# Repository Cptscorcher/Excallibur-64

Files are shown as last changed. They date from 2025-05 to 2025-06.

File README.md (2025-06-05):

# Excallibur-64
A reimagining of the seminal Excalibur 64 Computer
This is version 3 - yet to be tested but fixed a few things from version 2. Currently there are still some components that rely on 3rd party libraries and don't need to be, so in the process of removing them to make it more portable. 
There is no video yet, that is a separate beast. 

Goal for this project
=====================
Design build a new version of the  Excalibur 64. First major goal is to get all but the video going. So need to write firmware to take input from the keyboard output text via the serial port. 
Final version will have video as per original design.

Design requirements
==================
1. Needs to have the same look and feel of a real Excalibur 64. So the circuit for the sound and, parallel and keyboard is the same but with CMOS where possible.
2. Same goes for the video but need to think about a work around for the 6331-1 PROM.
3. There are some differences for practically and cost. For example using a single SRAM and single Flash ROM instead of two ROMs. Burning ROMs is a pain maybe when I do a 'pitch perfect' PCB I'll use DRAM and PROMS. The power supply is also different. At $25 I'm not using a LM323 for a +5 reg and since we are using a RS232 line driver IC there is no need for -12v. The reset circuit is different, that was simply because I don't understand how the original reset circuit worked. Its great to be authentic but a different power circuit isn't going to change the experience.

Future plans
============
1. Build a Disk Drive controller based on the WD2793 as per the original.
2. Build a HI-RES board.
3. Build some of the other board featured in the Excalibur 64 users group.
4. All the parts used on the original are still available so would be great to build one as the founders intended. All hail the founders!!

Credits
=======
All the original schematics + more is available from https://www.microbee-mspp.org/repository/ . Info from here was what this design is based on.

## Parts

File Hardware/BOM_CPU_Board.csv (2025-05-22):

Reference | Value | Qty | DNP
C7,C121,C123,C124,C125,C126 | 1uF | 6
C19,C101 | 4.7uF | 2
C25 | 56nF | 1
C26 | 10uF | 1
C102,C103,C104,C105,C106,C108,C109,C111,C112,C113,C114,C115,C116,C117,C118,C119,C120,C129,C130,C131 | 10nf | 20
C107,C128 | 33p | 2
C110 | 1000uF | 1
C122 | 100uF | 1
C127 | 100pf | 1
D1,D2,D3,D4,D5,D6,D7,D8,D21,D22,D104 | 1N4148 | 11
D101 | 5v | 1
D102 | 1N4448 | 1
D103 | 12v | 1
DZ101 | BZX79-B2V4 | 1
IC1 | 74HCT244 | 1
IC15 | 8253 | 1
IC16 | Z84C00 | 1
IC18 | 74HC139 | 1
IC22 | 8251 | 1
IC25,IC32 | 74HC138 | 2
IC27 | 74HC32 | 1
IC28 | 74HC00 | 1
IC29 | 74HC04 | 1
IC30 | 74HC02 | 1
IC31 | 74HC273 | 1
IC35 | 82C55A | 1
IC42 | LM348N | 1
IC49 | 74HC367 | 1
IC54 | 74HC123 | 1
IC56 | 74HC161 | 1
IC102 | MAX232 | 1
IC110 | SST39SF010 | 1
IC111 | HM62256ALSP | 1
J3 | Ext Clk | 1
J4 | Expansion | 1
J7 | Decoder | 1
J101 | CS Test Points | 1
J102 | Tx | 1
J103 | Rx | 1
J104 | SPEAKER (AUDIO) | 1
J105 | TTL Serial | 1
J107 | Power In | 1
J108 | CASSETTE | 1
J109 | RTS - DSR | 1
J110 | PARALLEL OUTPUT PORT | 1
J111 | Keyboard | 1
J112 | Serial | 1
LED1 | SST0 | 1
LED2 | SST1 | 1
LED3 | SST2 | 1
LED4 | Not Used | 1
LED101,LED103 | Red | 2
LED102,LED104 | Green | 2
Q1,Q102 | BC548 | 2
Q101 | 2N2222A-TO92 | 1
R17,R104,R110,R112,R113,RN101 | 10K | 6
R18,R23,R25,R111 | 2K2 | 4
R19,R21,R114 | 18K | 3
R20,R115 | 18 | 2
R22,R105 | 1K | 2
R24 | 68K | 1
R28,R29,R30,R31 | 4k7 | 4
R38 | 10 | 1
R39 | 820 | 1
R101 | 220 | 1
R102 | 100K | 1
R103,R106,RN2 | 4K7 | 3
R107 | 6K8 | 1
R108,R109,R116,R117,R142,R143,R144,R145 | 90 | 8
R118 | 560 | 1
R119 | 360 | 1
R120 | 1M | 1
SW101 | Reset | 1
TP101,XTAL2 | 16Mhz | 2
TP102 | TestPoint | 1
U101 | 74HC14 | 1
U102 | LM7805CT | 1
U103 | LM7812CT | 1

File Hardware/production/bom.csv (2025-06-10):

Designator | Footprint | Quantity | Value | LCSC Part #
C1 | CP_Radial_D14.0mm_P5.00mm | 1 | 1000Uf
C10, C11, C12, C13, C14, C15, C16, C17, C18, C19, C20, C21, C22, C23, C24, C27, C5, C6, C8, C9 | C_Disc_D4.3mm_W1.9mm_P5.00mm | 20 | 10nF
C121, C123, C124, C125, C126, C7 | CP_Radial_D6.3mm_P2.50mm | 6 | 1uF
C127 | C_Disc_D3.4mm_W2.1mm_P2.50mm | 1 | 100pf
C2, C3 | CP_Radial_D8.0mm_P5.00mm | 2 | 4.7uF
C25 | 0603 | 1 | 56nF
C26 | CP_Radial_D5.0mm_P2.50mm | 1 | 10uF
C29, C30 | C_Disc_D3.0mm_W1.6mm_P2.50mm | 2 | 33p
C4 | CP_Radial_D8.0mm_P5.00mm | 1 | 100uF
D1, D12, D13, D2, D3, D4, D5, D6, D7, D8 | D_DO-35_SOD27_P7.62mm_Horizontal | 10 | 1N4148
D10 | LED_D5.0mm | 1 | GREEN
D11 | D_DO-35_SOD27_P7.62mm_Horizontal | 1 | 1N4448
D14, D9 | LED_D5.0mm | 2 | RED
D15 | 1206 | 1 | SST0
D16 | 1206 | 1 | SST1
D17 | 1206 | 1 | SST2
D18 | 1206 | 1 | Not Used
DZ101 | D_DO-35_SOD27_P7.62mm_Horizontal | 1 | BZX79-B2V4
IC1 | DIP-20_W7.62mm_LongPads | 1 | 74HCT244
IC102 | DIP-16_W7.62mm_LongPads | 1 | MAX232
IC110 | DIP_Socket-32_W11.9_W12.7_W15.24_W17.78_W18.5_3M_232-1285-00-0602J | 1 | SST39SF010
IC111 | DIP-28_W15.24mm | 1 | HM62256ALSP
IC15 | DIP-24_W15.24mm | 1 | 8253
IC16 | DIP-40_W15.24mm_LongPads | 1 | Z80 CPU
IC18 | DIP-16_W7.62mm_Socket_LongPads | 1 | 74HC139
IC22 | DIP-28_W15.24mm_LongPads | 1 | 8251
IC25 | DIP-16_W7.62mm_LongPads | 1 | 74HC138
IC27 | DIP-14_W7.62mm_LongPads | 1 | 74HC32
IC29 | DIP-14_W7.62mm_Socket_LongPads | 1 | 74AHC04
IC31 | DIP-20_W7.62mm_Socket | 1 | 74HC273
IC32 | DIP-16_W7.62mm_Socket_LongPads | 1 | 74HC138
IC35 | DIP-40_W15.24mm | 1 | 82C55A
IC42 | DIP-14_W7.62mm_LongPads | 1 | LM348N
IC49 | DIP-16_W7.62mm_Socket_LongPads | 1 | 74HC367
IC54 | DIP-16_W7.62mm_LongPads | 1 | 74HC123
IC56 | DIP-16_W7.62mm_Socket_LongPads | 1 | 74HC161
J1 | DIN_5 | 1 | POWER
J101 | PinHeader_1x09_P2.54mm_Vertical | 1 | CS Test Points
J102 | PinHeader_1x02_P2.54mm_Vertical | 1 | Tx
J103 | PinHeader_1x02_P2.54mm_Vertical | 1 | Rx
J104 | PinSocket_1x03_P2.54mm_Vertical | 1 | SPEAKER
J105 | PinHeader_1x06_P2.54mm_Vertical | 1 | TTL Serial
J106 | PinHeader_1x03_P2.54mm_Vertical | 1 | UpperROM
J108 | DIN_5 | 1 | CASSETTE
J109 | PinHeader_1x02_P2.54mm_Vertical | 1 | RTS - DSR
J110 | IDC-Header_2x17_P2.54mm_Latch_Horizontal | 1 | PARALLEL OUTPUT PORT
J111 | PinHeader_2x08_P2.54mm_Vertical | 1 | Keyboard
J112 | DSUB-9_Pins_Horizontal_P2.77x2.84mm_EdgePinOffset4.94mm_Housed_MountingHolesOffset4.94mm | 1 | Serial
J2 | PinHeader_1x02_P2.54mm_Vertical | 1 | PC
J3 | PinHeader_1x04_P2.54mm_Vertical | 1 | Power In
J4 | PinHeader_2x22_P2.54mm_Vertical | 1 | Expansion
J7 | PinHeader_1x09_P2.54mm_Vertical | 1 | Decoder
LED101, LED103 | 1206 | 2 | Red
LED102, LED104 | 1206 | 2 | Green
Q1, Q2 | TO-92_HandSolder | 2 | BC548
Q101 | TO-92_Inline | 1 | BC548
R1, R10 | R_Axial_DIN0207_L6.3mm_D2.5mm_P10.16mm_Horizontal | 2 | 560
R107 | R_Axial_DIN0207_L6.3mm_D2.5mm_P10.16mm_Horizontal | 1 | 6K8
R108, R109, R116, R117, R142, R143, R144, R145 | 1206 | 8 | 90
R110, R112, R113, R17, R3 | R_Axial_DIN0207_L6.3mm_D2.5mm_P10.16mm_Horizontal | 5 | 10K
R111, R18, R23, R25 | R_Axial_DIN0207_L6.3mm_D2.5mm_P10.16mm_Horizontal | 4 | 2K2
R114, R19, R21 | R_Axial_DIN0207_L6.3mm_D2.5mm_P10.16mm_Horizontal | 3 | 18K
R115, R20 | R_Axial_DIN0207_L6.3mm_D2.5mm_P10.16mm_Horizontal | 2 | 18
R2 | R_Axial_DIN0207_L6.3mm_D2.5mm_P10.16mm_Horizontal | 1 | 220
R22, R4 | R_Axial_DIN0207_L6.3mm_D2.5mm_P10.16mm_Horizontal | 2 | 1K
R24 | R_Axial_DIN0207_L6.3mm_D2.5mm_P10.16mm_Horizontal | 1 | 68K
R38 | R_Axial_DIN0207_L6.3mm_D2.5mm_P10.16mm_Horizontal | 1 | 10
R39 | R_Axial_DIN0207_L6.3mm_D2.5mm_P10.16mm_Horizontal | 1 | 820
R5, R6 | R_Axial_DIN0207_L6.3mm_D2.5mm_P10.16mm_Horizontal | 2 | 4.7k
R7 | R_Axial_DIN0207_L6.3mm_D2.5mm_P10.16mm_Horizontal | 1 | 100k
R8 | R_Axial_DIN0207_L6.3mm_D2.5mm_P10.16mm_Horizontal | 1 | 1M
R9 | R_Axial_DIN0207_L6.3mm_D2.5mm_P10.16mm_Horizontal | 1 | 360
RN1, RN101 | R_Array_SIP5 | 2 | 10K
RN2 | R_Array_SIP9 | 1 | 10k
SW1 | MFS201N-16-Z_NDC | 1 | Power
SW101 | Tact_switch_angled | 1 | Reset
TP1, TP102 | TestPoint_Plated_Hole_D2.0mm | 2 | GND
TP101 | TestPoint_Loop_D1.80mm_Drill1.0mm_Beaded | 1 | 16Mhz
U101 | DIP-14_W7.62mm_Socket_LongPads | 1 | 74AHCU04
U104 | DIP-14_W7.62mm_Socket_LongPads | 1 | 74HC86
U2 | TO-220-3_Vertical | 1 | L7805
XTAL2 | Crystal_HC49-U_Vertical | 1 | 16Mhz

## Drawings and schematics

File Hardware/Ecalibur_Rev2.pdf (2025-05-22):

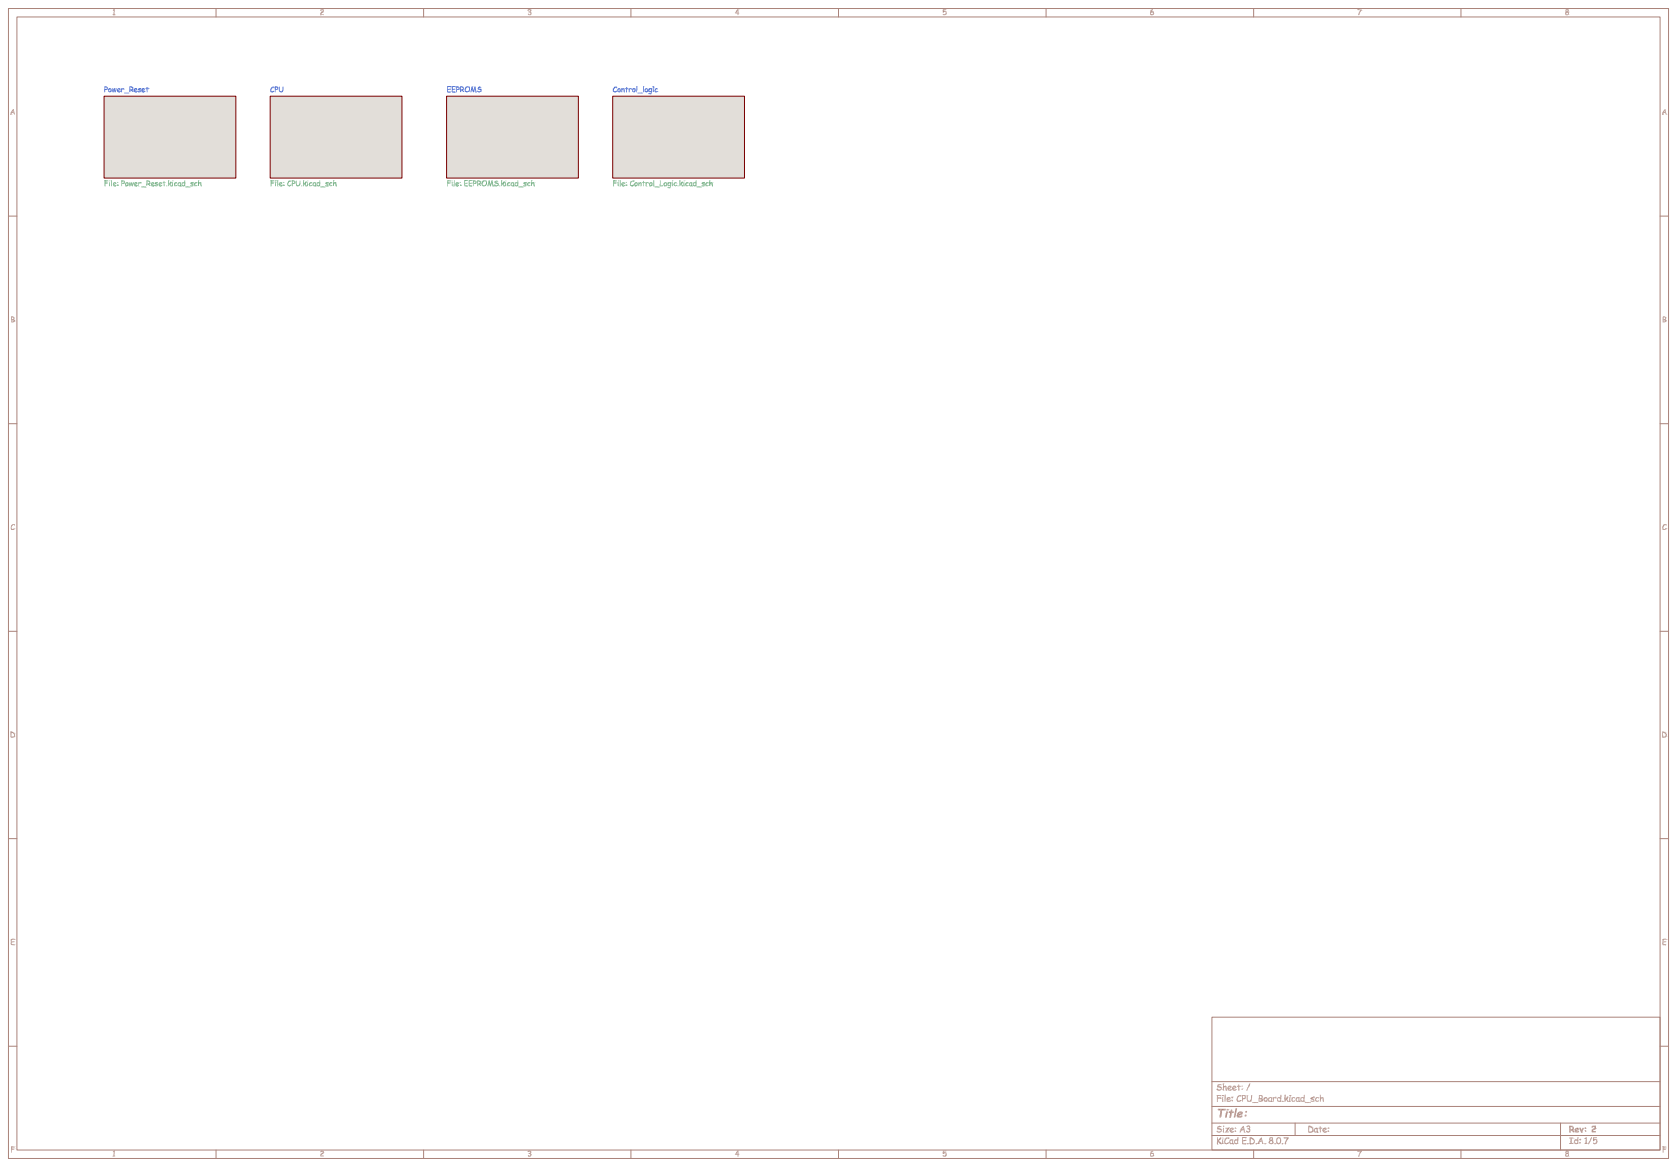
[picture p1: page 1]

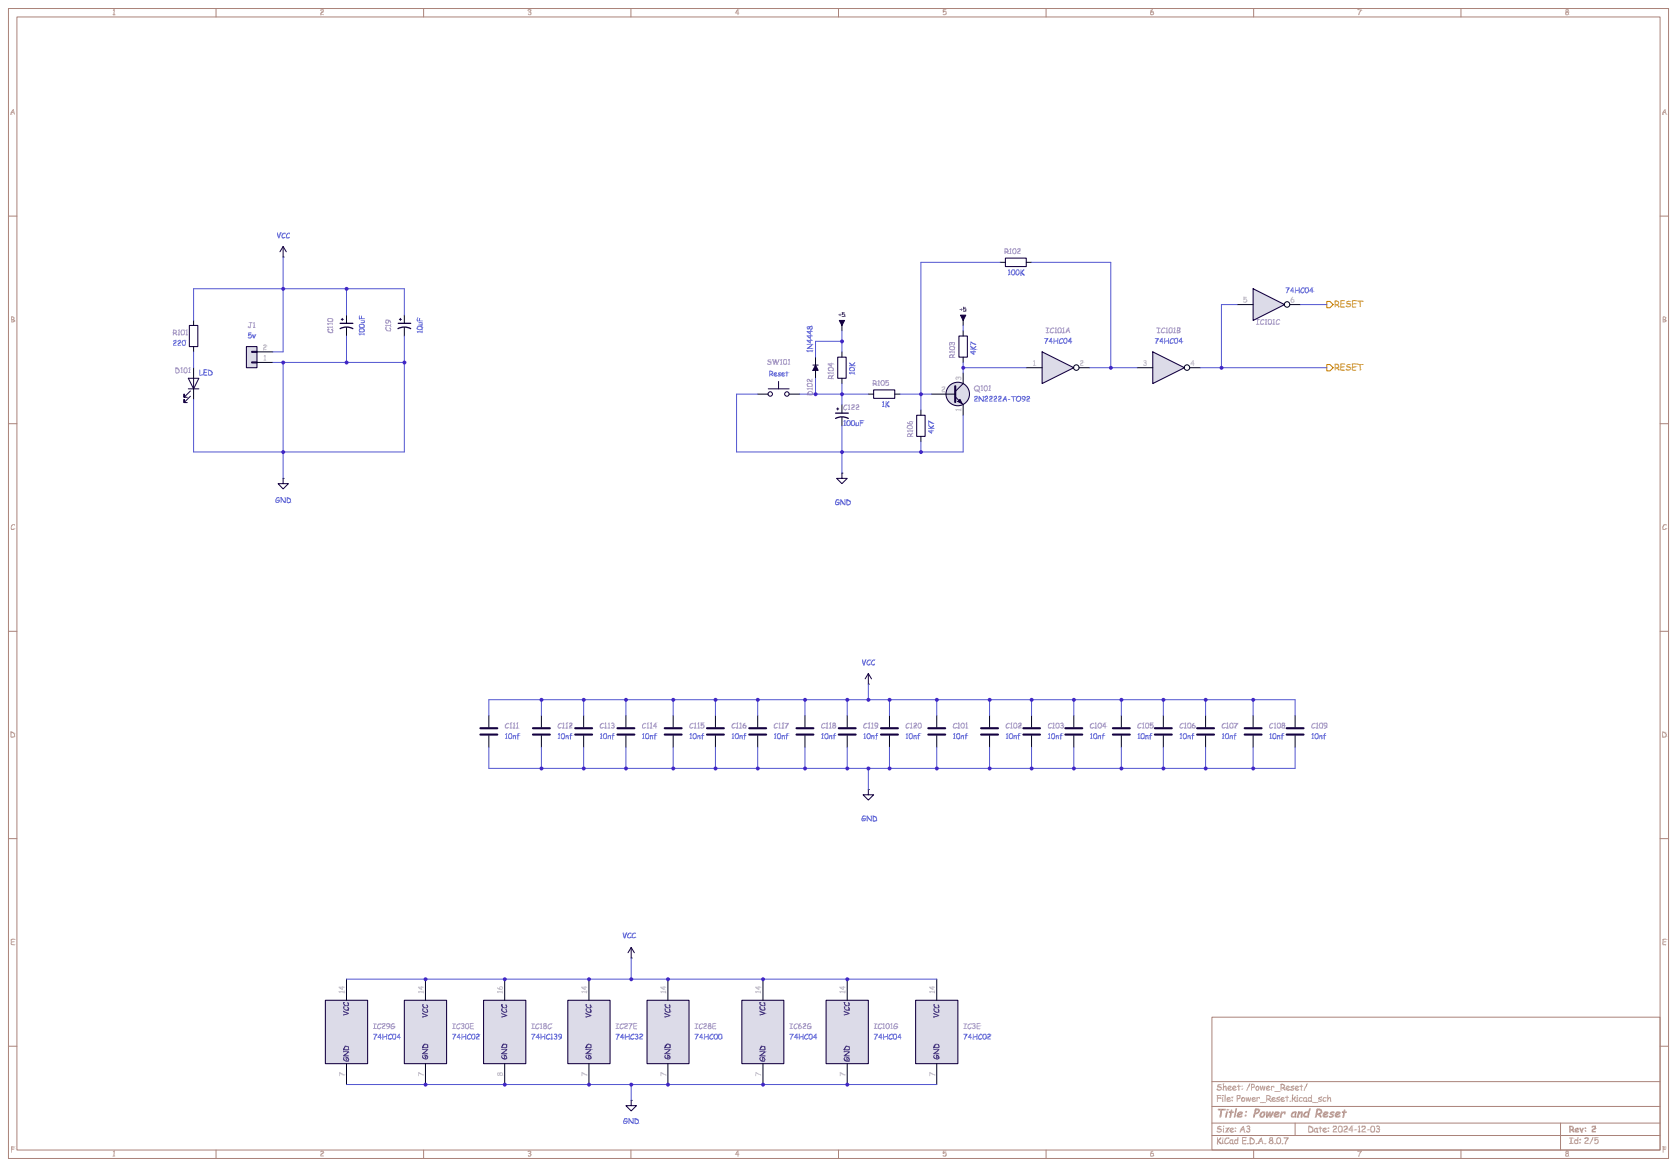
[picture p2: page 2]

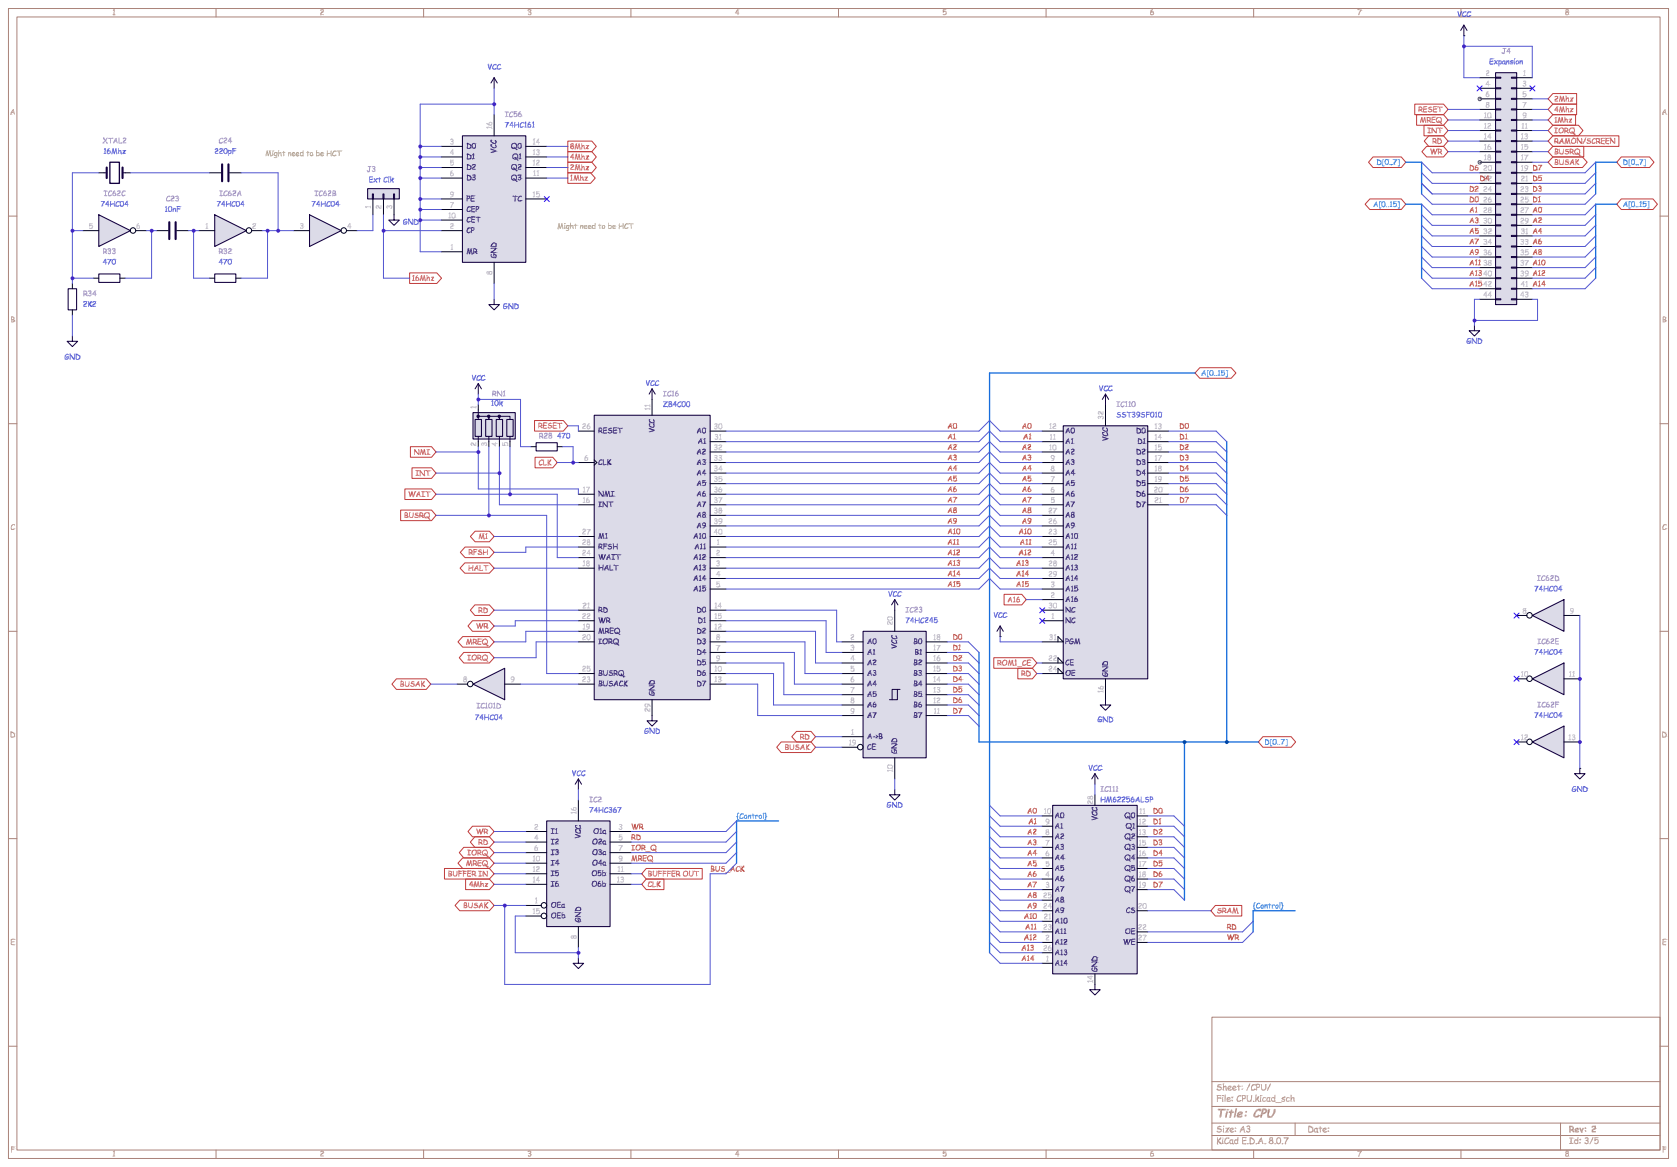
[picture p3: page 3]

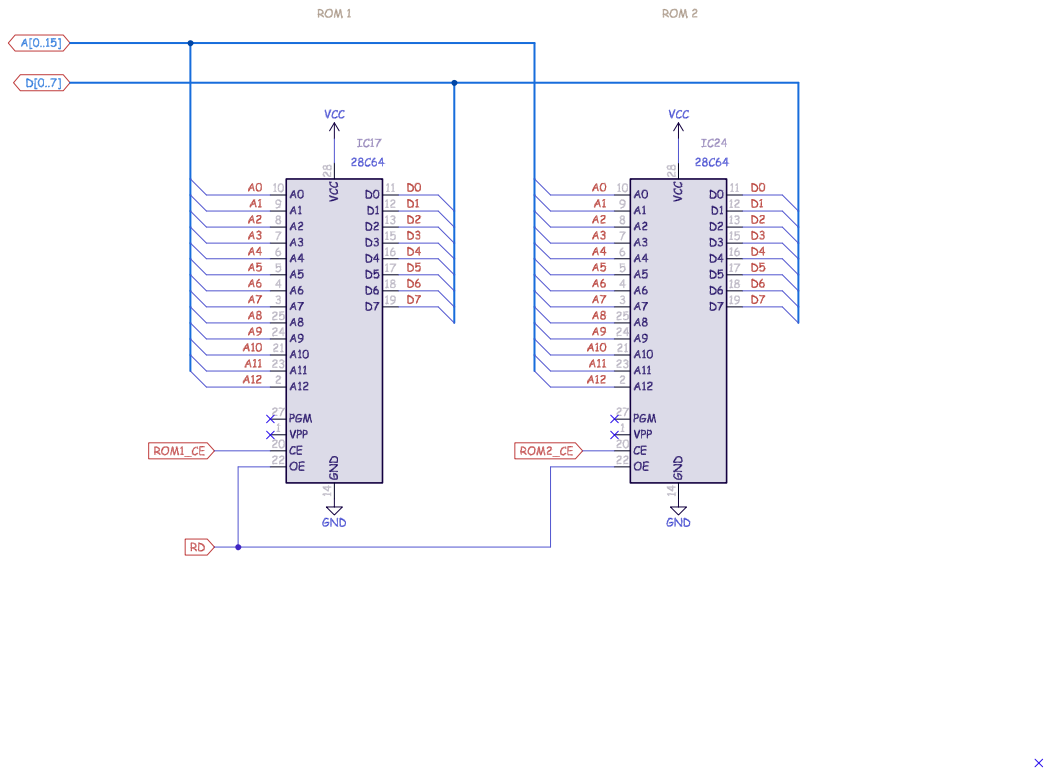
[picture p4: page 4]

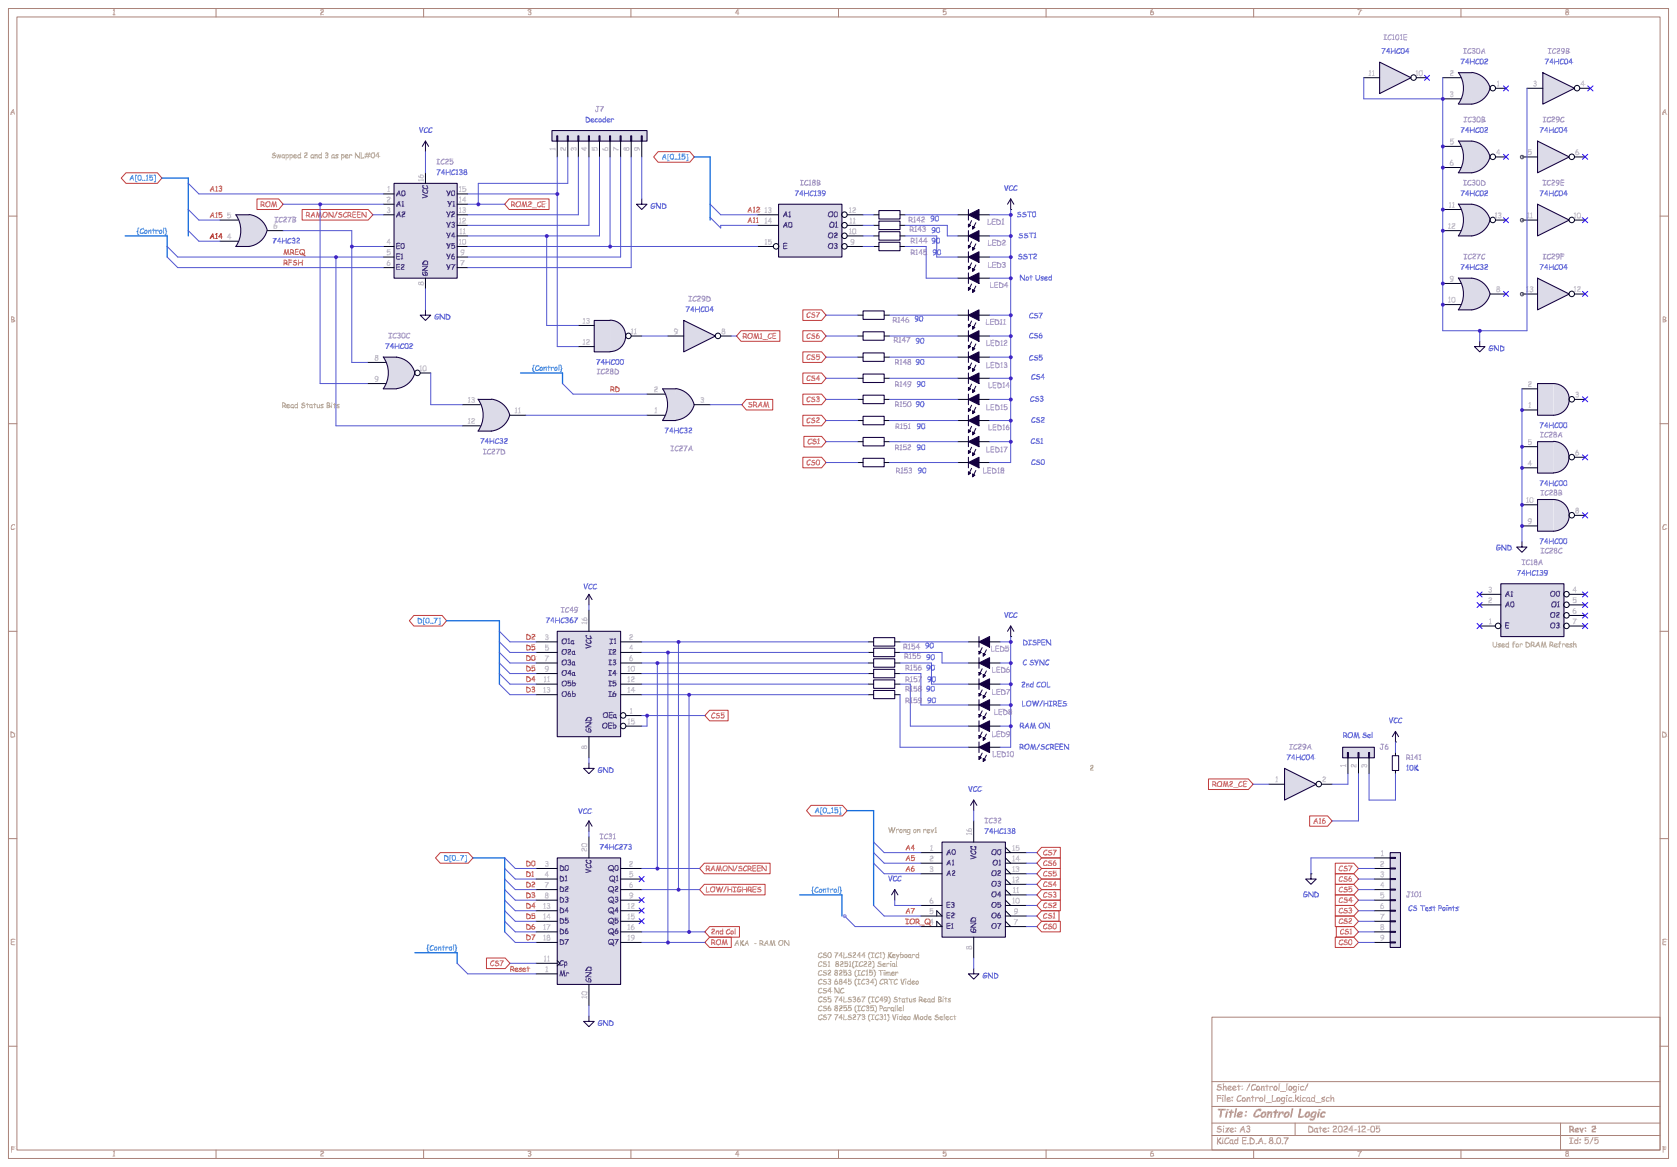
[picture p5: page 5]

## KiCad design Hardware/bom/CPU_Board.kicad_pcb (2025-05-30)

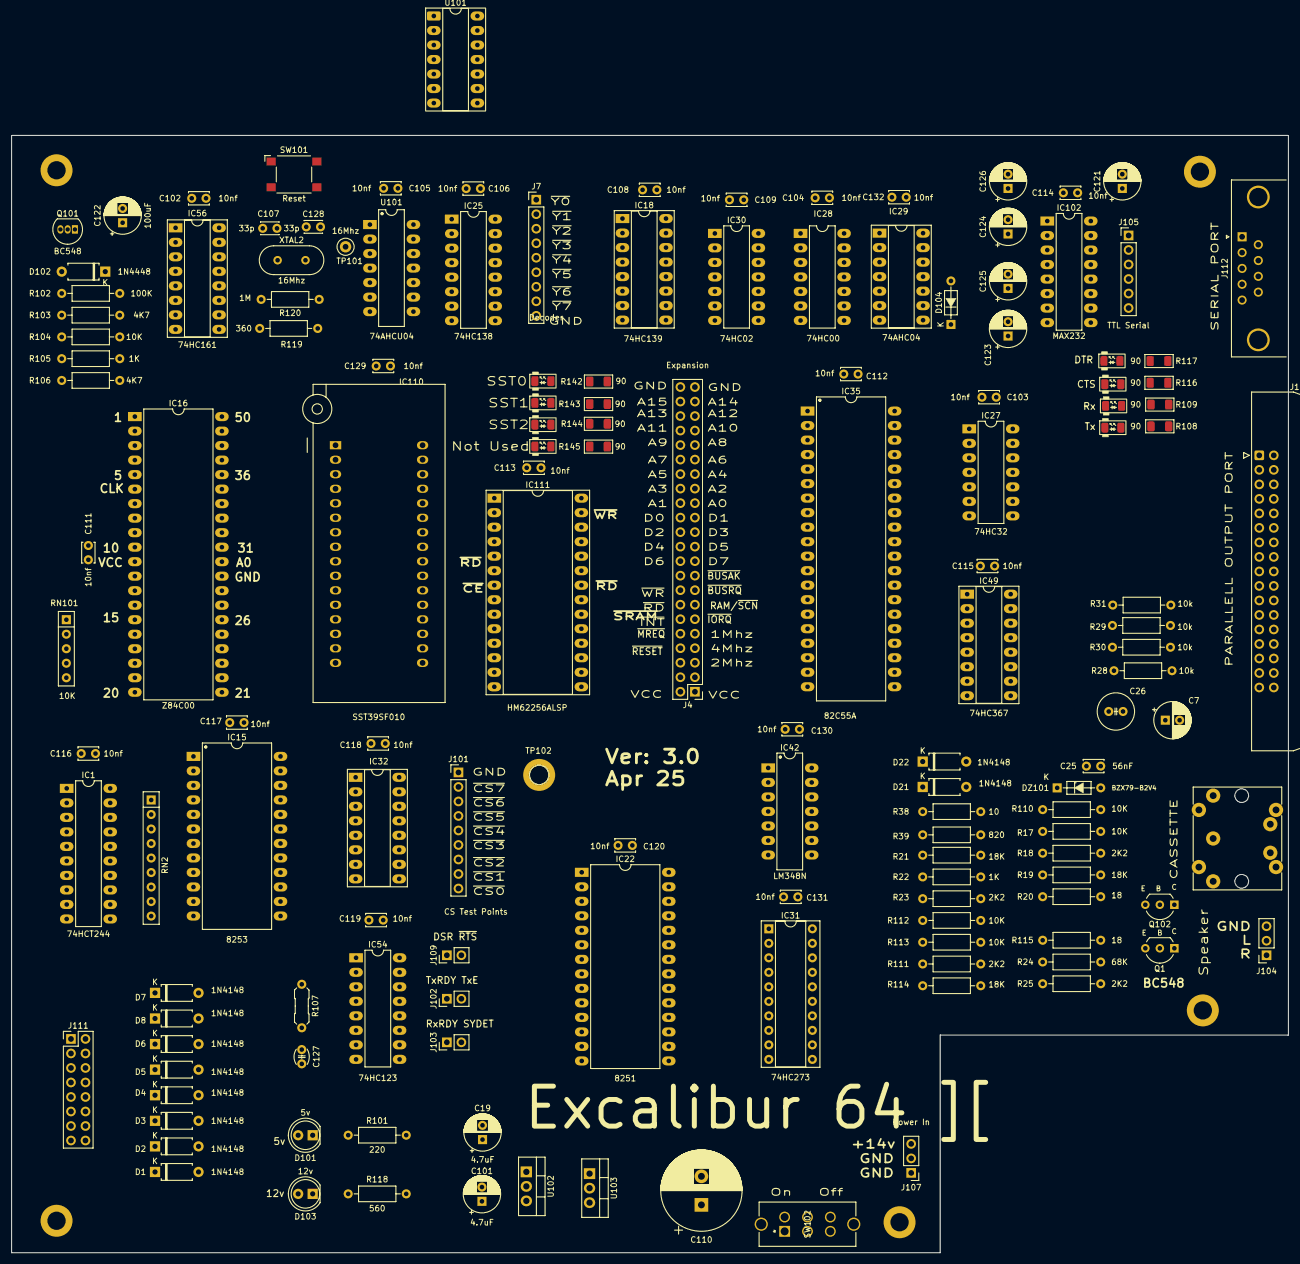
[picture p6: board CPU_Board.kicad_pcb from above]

Board: 2 copper layers, 223.5 x 195.6 mm, 150 parts (0 on the bottom side), 180 nets, no tracks yet.

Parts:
C7, C121, C123, C124, C125, C126: 1uF; CP_Radial_D6.3mm_P2.50mm
C19, C101: 4.7uF; CP_Radial_D6.3mm_P2.50mm
C25: 56nF; C_Disc_D3.4mm_W2.1mm_P2.50mm
C26: 10uF; C_Radial_D6.3mm_H5.0mm_P2.50mm
C102, C103, C104, C105, C106, C108, C109, C111, C112, C113, C114, C115, C116, C117, C118, C119, C120, C129, C130, C131, C132: 10nf; C_Disc_D3.4mm_W2.1mm_P2.50mm
C107, C128: 33p; C_Disc_D3.0mm_W2.0mm_P2.50mm
C110: 1000uF; CP_Radial_D14.0mm_P5.00mm
C122: 100uF; CP_Radial_D6.3mm_P2.50mm
C127: 100pf; C_Disc_D3.8mm_W2.6mm_P2.50mm
D1, D2, D3, D4, D5, D6, D7, D8, D21, D22: 1N4148; D_A-405_P7.62mm_Horizontal
D101: 5v; LED_D5.0mm
D102: 1N4448; D_A-405_P7.62mm_Horizontal
D103: 12v; LED_D5.0mm
D104: 1N4148; D_DO-35_SOD27_P7.62mm_Horizontal
DZ101: BZX79-B2V4; D_DO-35_SOD27_P7.62mm_Horizontal_Zener
IC1: 74HCT244; DIP-20_W7.62mm_LongPads
IC15: 8253; DIP-24_W15.24mm_LongPads
IC16: Z84C00; DIP-40_W15.24mm_LongPads
IC18: 74HC139; DIP-16_W7.62mm_Socket_LongPads
IC22: 8251; DIP-28_W15.24mm_LongPads
IC25: 74HC138; DIP-16_W7.62mm_LongPads
IC27: 74HC32; DIP-14_W7.62mm_LongPads
IC28: 74HC00; DIP-14_W7.62mm_LongPads
IC29: 74AHC04; DIP-14_W7.62mm_Socket_LongPads
IC30: 74HC02; DIP-14_W7.62mm_LongPads
IC31: 74HC273; DIP-20_W7.62mm_Socket
IC32: 74HC138; DIP-16_W7.62mm_Socket_LongPads
IC35: 82C55A; DIP-40_W15.24mm_LongPads
IC42: LM348N; DIP-14_W7.62mm_LongPads
IC49: 74HC367; DIP-16_W7.62mm_Socket_LongPads
IC54: 74HC123; DIP-16_W7.62mm_LongPads
IC56: 74HC161; DIP-16_W7.62mm_Socket_LongPads
IC102: MAX232; DIP-16_W7.62mm_LongPads
IC110: SST39SF010; DIP_Socket-32_W11.9_W12.7_W15.24_W17.78_W18.5_3M_232-1285-0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
IC111: HM62256ALSP; DIP-28_W15.24mm_Socket_LongPads
J4: Expansion; PinHeader_2x22_P2.54mm_Vertical
J7: Decoder; PinHeader_1x09_P2.54mm_Vertical
J101: CS Test Points; PinHeader_1x09_P2.54mm_Vertical
J102: Tx; PinHeader_1x02_P2.54mm_Vertical
J103: Rx; PinHeader_1x02_P2.54mm_Vertical
J104: SPEAKER (AUDIO); PinSocket_1x03_P2.54mm_Vertical
J105: TTL Serial; PinHeader_1x06_P2.54mm_Vertical
J107: Power In; PinHeader_1x03_P2.54mm_Vertical
J108: CASSETTE; DIN_5
J109: RTS - DSR; PinHeader_1x02_P2.54mm_Vertical
J110: PARALLEL OUTPUT PORT; IDC-Header_2x17_P2.54mm_Latch_Horizontal
J111: Keyboard; PinHeader_2x08_P2.54mm_Vertical
J112: Serial; DSUB-9_Female_Horizontal_P2.77x2.84mm_EdgePinOffset4.94mm_H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
LED1: SST0; LED_1206_3216Metric
LED2: SST1; LED_1206_3216Metric
LED3: SST2; LED_1206_3216Metric
LED4: Not Used; LED_1206_3216Metric
LED101, LED103: Red; LED_1206_3216Metric
LED102, LED104: Green; LED_1206_3216Metric
Q1, Q102: BC548; TO-92_Inline_Wide_CBE
Q101: BC548; TO-92_Inline
R17, R104, R110, R112, R113: 10K; R_Axial_DIN0207_L6.3mm_D2.5mm_P10.16mm_Horizontal
R18, R23, R25, R111: 2K2; R_Axial_DIN0207_L6.3mm_D2.5mm_P10.16mm_Horizontal
R19, R21, R114: 18K; R_Axial_DIN0207_L6.3mm_D2.5mm_P10.16mm_Horizontal
R20, R115: 18; R_Axial_DIN0207_L6.3mm_D2.5mm_P10.16mm_Horizontal
R22, R105: 1K; R_Axial_DIN0207_L6.3mm_D2.5mm_P10.16mm_Horizontal
R24: 68K; R_Axial_DIN0207_L6.3mm_D2.5mm_P10.16mm_Horizontal
R28, R29, R30, R31: 10k; R_Axial_DIN0207_L6.3mm_D2.5mm_P10.16mm_Horizontal
R38: 10; R_Axial_DIN0207_L6.3mm_D2.5mm_P10.16mm_Horizontal
R39: 820; R_Axial_DIN0207_L6.3mm_D2.5mm_P10.16mm_Horizontal
R101: 220; R_Axial_DIN0207_L6.3mm_D2.5mm_P10.16mm_Horizontal
R102: 100K; R_Axial_DIN0207_L6.3mm_D2.5mm_P10.16mm_Horizontal
R103, R106: 4K7; R_Axial_DIN0207_L6.3mm_D2.5mm_P10.16mm_Horizontal
R107: 6K8; R_Axial_DIN0207_L6.3mm_D2.5mm_P7.62mm_Horizontal
R108, R109, R116, R117, R142, R143, R144, R145: 90; R_1206_3216Metric_Pad1.30x1.75mm_HandSolder
R118: 560; R_Axial_DIN0207_L6.3mm_D2.5mm_P10.16mm_Horizontal
R119: 360; R_Axial_DIN0207_L6.3mm_D2.5mm_P10.16mm_Horizontal
R120: 1M; R_Axial_DIN0207_L6.3mm_D2.5mm_P10.16mm_Horizontal
REF01, REF02, REF04, REF05, REF06: MountingHole_3.2mm_M3_DIN965_Pad
RN2: 10k; R_Array_SIP9
RN101: 10K; R_Array_SIP5
SW101: Reset; SW_SPST_Omron_B3FS-100xP
SW102: Power; MFS201N-16-Z_NDC
TP101: 16Mhz; TestPoint_Loop_D1.80mm_Drill1.0mm_Beaded
TP102: TestPoint; TestPoint_Plated_Hole_D2.0mm
U101: 74AHCU04; DIP-14_W7.62mm_LongPads
U101#2: 74AHCU04; DIP-14_W7.62mm_Socket_LongPads
U102: LM7805CT; TO-220-3_Vertical
U103: LM7812CT; TO-220-3_Vertical
XTAL2: 16Mhz; Crystal_HC49-U_Vertical

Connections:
1Mhz: IC56.11 (Q3), J4.9
2Mhz: IC15.9 (CLK0), IC15.15 (CLK1), IC15.18 (CLK2), IC22.20 (CLK), IC56.12 (Q2), J4.5
2nd Col: IC31.16 (Q6), IC49.14 (I6)
4Mhz: IC16.6 (~CLK), IC56.13 (Q1), J4.7
16Mhz: IC56.2 (CP), TP101.1, U101.2, U101#2.4
+12V: R19.1, R20.1, R114.1, R115.1, R118.1, U102.1 (IN), U103.3 (OUT)
/CPU/~BUS_REQ: IC16.25 (~BUSRQ), RN101.4 (R3)
/Control_logic/~MREQ: IC25.5 (~E1), IC27.12
/Power_Reset/POWER_IN: J107.3, SW102.5
/Power_Reset/POWER_OUT: C19.1, C110.1, SW102.6, U103.1 (IN)
/Power_Reset/RESET: U101.6, U101.9, U101#2.8, U101#2.11
/Power_Reset/~RESET: U101.8, U101#2.10
A0: IC15.19 (A0), IC16.30 (A0), IC22.12 (C/~D), IC35.9 (A0), IC110.12 (A0), IC111.10 (A0), J4.27
A1: IC15.20 (A1), IC16.31 (A1), IC35.8 (A1), IC110.11 (A1), IC111.9 (A1), J4.28
A2: IC16.32 (A2), IC110.10 (A2), IC111.8 (A2), J4.29
A3: IC16.33 (A3), IC110.9 (A3), IC111.7 (A3), J4.30
A4: IC16.34 (A4), IC32.1 (A0), IC110.8 (A4), IC111.6 (A4), J4.31
A5: IC16.35 (A5), IC32.2 (A1), IC110.7 (A5), IC111.5 (A5), J4.32
A6: IC16.36 (A6), IC32.3 (A2), IC110.6 (A6), IC111.4 (A6), J4.33
A7: IC16.37 (A7), IC32.5 (E2), IC110.5 (A7), IC111.3 (A7), J4.34
A8: IC16.38 (A8), IC110.27 (A8), IC111.25 (A8), J4.35
A9: IC16.39 (A9), IC110.26 (A9), IC111.24 (A9), J4.36
A10: IC16.40 (A10), IC110.23 (A10), IC111.21 (A10), J4.37
A11: IC16.1 (A11), IC18.14 (A0), IC110.25 (A11), IC111.23 (A11), J4.38
A12: IC16.2 (A12), IC18.13 (A1), IC110.4 (A12), IC111.2 (A12), J4.39
A13: IC16.3 (A13), IC25.1 (A0), IC110.28 (A13), IC111.26 (A13), J4.40
A14: IC16.4 (A14), IC110.29 (A14), IC111.1 (A14), J4.41
A15: IC16.5 (A15), IC27.5, IC110.3 (A15), J4.42
BUSY: IC35.14 (PC0), J110.11, R30.2
COL0: IC1.11 (2A3), J111.7, RN2.9 (R8)
COL1: IC1.8 (1A3), J111.8, RN2.5 (R4)
COL2: IC1.13 (2A2), J111.5, RN2.8 (R7)
COL3: IC1.6 (1A2), J111.6, RN2.4 (R3)
COL4: IC1.15 (2A1), J111.3, RN2.7 (R6)
COL5: IC1.4 (1A1), J111.4, RN2.3 (R2)
COL6: IC1.17 (2A0), J111.1, RN2.6 (R5)
COL7: IC1.2 (1A0), J111.2, RN2.2 (R1)
D0: IC1.18 (1Y0), IC15.8 (D0), IC16.14 (D0), IC22.8 (D7), IC31.3 (D0), IC35.34 (D0), IC49.7 (O3a), IC110.13 (D0), IC111.11 (Q0), J4.26
D1: IC1.16 (1Y1), IC15.7 (D1), IC16.15 (D1), IC22.7 (D6), IC31.4 (D1), IC35.33 (D1), IC110.14 (D1), IC111.12 (Q1), J4.25
D2: IC1.14 (1Y2), IC15.6 (D2), IC16.12 (D2), IC22.6 (D5), IC31.7 (D2), IC35.32 (D2), IC49.3 (O1a), IC110.15 (D2), IC111.13 (Q2), J4.24
D3: IC1.12 (1Y3), IC15.5 (D3), IC16.8 (D3), IC22.5 (D4), IC31.8 (D3), IC35.31 (D3), IC49.13 (O6b), IC110.17 (D3), IC111.15 (Q3), J4.23
D4: IC1.3 (2Y0), IC15.4 (D4), IC16.7 (D4), IC22.2 (D3), IC31.13 (D4), IC35.30 (D4), IC49.11 (O5b), IC110.18 (D4), IC111.16 (Q4), J4.22
D5: IC1.5 (2Y1), IC15.3 (D5), IC16.9 (D5), IC22.1 (D2), IC31.14 (D5), IC35.29 (D5), IC49.5 (O2a), IC49.9 (O4a), IC110.19 (D5), IC111.17 (Q5), J4.21
D6: IC1.7 (2Y2), IC15.2 (D6), IC16.10 (D6), IC22.28 (D1), IC31.17 (D6), IC35.28 (D6), IC110.20 (D6), IC111.18 (Q6), J4.20
D7: IC1.9 (2Y3), IC15.1 (D7), IC16.13 (D7), IC22.27 (D0), IC31.18 (D7), IC35.27 (D7), IC110.21 (D7), IC111.19 (Q7), J4.19
GND: C7.2, C19.2, C101.2, C102.2, C103.2, C104.2, C105.2, C106.2, C107.1, C108.2, C109.2, C110.2, C111.2, C112.2, C113.2, C114.2, C115.2, C116.2, C117.2, C118.2, C119.2, C120.2, C121.2, C122.2, C126.2, C128.2, C129.2, C130.2, C131.2, C132.2, D101.2 (K), D103.2 (K), DZ101.2 (A), IC1.10 (GND), IC15.12 (GND), IC16.29 (GND), IC18.8 (GND), IC22.4 (GND), IC25.6 (E2), IC25.8 (GND), IC27.7 (GND), IC28.1, IC28.2, IC28.4, IC28.5, IC28.7 (GND), IC29.7 (GND), IC29.11, IC29.13, IC30.2, IC30.3, IC30.5, IC30.6, IC30.7 (GND), IC30.11, IC30.12, IC31.10 (GND), IC32.8 (GND), IC35.7 (GND), IC42.11 (V-), IC49.8 (GND), IC54.8 (GND), IC56.8 (GND), IC102.15 (GND), IC110.16 (GND), IC111.14 (GND), J4.43, J4.44, J7.9, J101.1, J104.3, J105.1, J107.1, J107.2, J110.14, J110.16, J110.19, J110.20, J110.21, J110.22, J110.23, J110.24, J110.25, J110.26, J110.27, J110.28, J110.29, J110.30, J110.33, J112.0 (PAD), J112.5, Q101.3 (E), R21.1, R23.2, R38.2, R106.2, R108.2, R109.2, R110.1, R112.1, R116.2, R117.2, REF01.1, REF02.1, REF04.1, REF05.1, REF06.1, SW101.1, TP102.1, U101.7 (GND), U101.13, U101#2.7 (GND), U102.2, U103.2
unnamed: C25.1, R21.2, R22.2
unnamed: C25.2, D21.1, D22.2
unnamed: C26.1, IC42.1
unnamed: C26.2, R39.1
unnamed: C107.2, R120.2, U101#2.1, XTAL2.1
unnamed: C122.1, D102.1, R104.2, R105.2, SW101.2
unnamed: C128.1, R119.1, XTAL2.2
unnamed: D21.2, D22.1, J108.2, J108.3
unnamed: D101.1 (A), R101.2
unnamed: D103.1 (A), R118.2
unnamed: DZ101.1 (K), IC35.17 (PC3), R25.1
unnamed: IC15.10 (OUT0), IC42.10 (+)
unnamed: IC15.17 (OUT2), IC42.13 (-)
unnamed: IC16.17 (~NMI), RN101.2 (R1)
unnamed: IC16.24 (~WAIT), RN101.5 (R4)
unnamed: IC18.15 (E), IC25.10 (~Y5), J7.6
unnamed: IC18.12 (O0), R142.1
unnamed: IC18.11 (O1), R143.1
unnamed: IC18.10 (O2), R144.1
unnamed: IC18.9 (O3), R145.1
unnamed: IC22.14 (RxRDY), J103.1
unnamed: IC22.16 (SYDET), J103.2
unnamed: IC22.18 (TxE), J102.2
unnamed: IC22.15 (TxRDY), J102.1
unnamed: IC22.22 (~DSR), J109.1
unnamed: IC22.23 (~RTS), J109.2
unnamed: IC25.4 (~E0), IC27.6, IC30.8
unnamed: IC25.15 (~Y0), IC28.12, J7.1
unnamed: IC25.13 (~Y2), J7.3
unnamed: IC25.12 (~Y3), J7.4
unnamed: IC25.11 (~Y4), IC28.13, J7.5
unnamed: IC25.9 (~Y6), J7.7
unnamed: IC25.7 (~Y7), J7.8
unnamed: IC27.1, IC27.11
unnamed: IC27.10, IC28.8
unnamed: IC27.13, IC30.10
unnamed: IC28.11, IC29.9
unnamed: D8.2, IC35.18 (PB0)
unnamed: D7.2, IC35.19 (PB1)
unnamed: D6.2, IC35.20 (PB2)
unnamed: D5.2, IC35.21 (PB3)
unnamed: D4.2, IC35.22 (PB4)
unnamed: D3.2, IC35.23 (PB5)
unnamed: D2.2, IC35.24 (PB6)
unnamed: D1.2, IC35.25 (PB7)
unnamed: IC27.8, IC35.15 (PC1)
unnamed: IC35.10 (PC7), IC42.3 (+)
unnamed: IC42.7, R24.1, R25.2
unnamed: IC42.8, R17.2, R18.1
unnamed: IC42.14, R111.1, R113.2
unnamed: C7.1, IC42.2 (-)
unnamed: IC42.5 (+), R23.1, R24.2
unnamed: IC42.6 (-), R22.1
unnamed: IC42.9 (-), R17.1, R110.2
unnamed: IC42.12 (+), R112.2, R113.1
unnamed: C127.1, IC54.6 (Cext)
unnamed: C127.2, IC54.7 (RCext), R107.2
unnamed: C124.1, IC102.1 (C1+)
unnamed: C124.2, IC102.3 (C1-)
unnamed: C125.1, IC102.4 (C2+)
unnamed: C125.2, IC102.5 (C2-)
unnamed: IC102.13 (R1IN), J112.2
unnamed: IC22.3 (RxD), IC102.12 (R1OUT), J105.5, LED102.2 (A)
unnamed: IC102.8 (R2IN), J112.8
unnamed: IC22.17 (~CTS), IC102.9 (R2OUT), J105.2, LED101.1 (K)
unnamed: IC22.19 (TxD), IC102.11 (T1IN), J105.4, LED103.2 (A)
unnamed: IC102.14 (T1OUT), J112.7
unnamed: IC22.24 (~DTR), IC102.10 (T2IN), J105.6, LED104.1 (K)
unnamed: IC102.7 (T2OUT), J112.3
unnamed: C126.1, IC102.2 (VS+)
unnamed: C123.2, IC102.6 (VS-)
unnamed: IC29.6, IC110.2 (A16)
unnamed: J104.1, Q1.1 (C)
unnamed: J104.2, Q102.1 (C)
unnamed: J108.4, J108.5, R38.1, R39.2
unnamed: LED1.1 (K), R142.2
unnamed: LED2.1 (K), R143.2
unnamed: LED3.1 (K), R144.2
unnamed: LED4.1 (K), R145.2
unnamed: LED101.2 (A), R116.1
unnamed: LED102.1 (K), R109.1
unnamed: LED103.1 (K), R108.1
unnamed: LED104.2 (A), R117.1
unnamed: Q1.2 (B), R18.2, R19.2
unnamed: Q1.3 (E), R20.2
unnamed: Q101.2 (B), R102.2, R105.1, R106.1
unnamed: Q101.1 (C), R103.2, U101.3, U101#2.5
unnamed: Q102.2 (B), R111.2, R114.2
unnamed: Q102.3 (E), R115.2
unnamed: R102.1, U101.4, U101.5, U101#2.6, U101#2.9
unnamed: R119.2, R120.1, U101#2.2, U101#2.3
OUT PAPER: IC27.9, J110.12, R29.2
PD0: IC35.4 (PA0), J110.2
PD1: IC35.3 (PA1), J110.3
PD2: IC35.2 (PA2), J110.4
PD3: IC35.1 (PA3), J110.5
PD4: IC35.40 (PA4), J110.6
PD5: IC35.39 (PA5), J110.7
PD6: IC35.38 (PA6), J110.8
PD7: IC35.37 (PA7), J110.9
RAMON/~SCREEN: IC25.3 (A2), IC31.2 (Q0), IC49.6 (I3), J4.13
READY: IC35.16 (PC2), J110.10, R31.2
RESET: IC22.21 (Reset), IC35.35 (RESET)
ROW0: D8.1, J111.10
ROW1: D7.1, J111.9
ROW2: D6.1, J111.12
ROW3: D5.1, J111.11
ROW4: D4.1, J111.14
ROW5: D3.1, J111.13
ROW6: D2.1, J111.16
ROW7: D1.1, J111.15
UART_CLK: IC15.13 (OUT1), IC22.9 (~TxC), IC22.25 (~RxC)
UNIT SEL: IC28.9, IC28.10, J110.13, R28.2
VCC: C101.1, C102.1, C103.1, C104.1, C105.1, C106.1, C108.1, C109.1, C111.1, C112.1, C113.1, C114.1, C115.1, C116.1, C117.1, C118.1, C119.1, C120.1, C121.1, C123.1, C129.1, C130.1, C131.1, C132.1, D102.2, IC1.20 (VCC), IC15.24 (VCC), IC16.11 (VCC), IC18.16 (VCC), IC22.26 (Vcc), IC25.16 (VCC), IC27.14 (VCC), IC28.14 (VCC), IC29.14 (VCC), IC30.14 (VCC), IC31.20 (VCC), IC32.6 (E3), IC32.16 (VCC), IC35.26 (VCC), IC49.16 (VCC), IC54.10 (B), IC54.11 (Clr), IC54.16 (VCC), IC56.1 (~MR), IC56.3 (D0), IC56.4 (D1), IC56.5 (D2), IC56.6 (D3), IC56.7 (CEP), IC56.9 (~PE), IC56.10 (CET), IC56.16 (VCC), IC102.16 (VCC), IC110.31 (PGM), IC110.32 (VCC), IC111.28 (VCC), J4.1, J4.2, J105.3, LED1.2 (A), LED2.2 (A), LED3.2 (A), LED4.2 (A), R28.1, R29.1, R30.1, R31.1, R101.1, R103.1, R104.1, R107.1, RN2.1 (common), RN101.1 (common), U101.14 (VCC), U101#2.14 (VCC), U102.3 (OUT)
~CS0: IC1.1 (1OE), IC1.19 (2OE), IC32.7 (O7), J101.9
~CS1: IC22.11 (~CS), IC32.9 (O6), J101.8
~CS2: IC15.21 (~CS), IC32.10 (O5), IC54.9 (A), J101.7
~CS3: IC32.11 (O4), J101.6
~CS4: IC32.12 (O3), J101.5
~CS5: IC32.13 (O2), IC49.1 (OEa), IC49.15 (OEb), J101.4
~CS6: IC32.14 (O1), IC35.6 (~CS), J101.3
~CS7: IC31.11 (Cp), IC32.15 (O0), J101.2
~DATA STROBE: IC35.13 (PC4), J110.1
~INT: IC16.16 (~INT), J4.12, RN101.3 (R2)
~LOW/HIGHRES: IC31.6 (Q2), IC49.2 (I1)
~MREQ: IC16.19 (~MREQ), J4.10
~Q: IC15.23 (~WR), IC54.12 (~Q)
~RD: IC15.22 (~RD), IC16.21 (~RD), IC22.13 (~RD), IC35.5 (~RD), IC110.24 (OE), IC111.22 (~OE), J4.14
~RESET: IC16.26 (~RESET), J4.8
~ROM1_CE: D104.1 (K), IC29.8, IC110.22 (CE)
~ROM2_CE: D104.2 (A), IC25.14 (~Y1), IC29.5, J7.2
~ROM: IC25.2 (A1), IC30.9, IC31.19 (Q7), IC49.4 (I2)
~SRAM: IC27.3, IC111.20 (~CS)
~WR: IC16.22 (~WR), IC22.10 (~WR), IC35.36 (~WR), IC111.27 (~WE), J4.16

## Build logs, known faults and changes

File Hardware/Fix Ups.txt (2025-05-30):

IC16 20 to J4 	11 IORQ
IC25 6  to IC25 6  5v 
IC27 2  to J4 	14 /RD
IC27 4  to J4 	41 A14

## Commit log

2025-05-22 Add files via upload
    Initial Commit
    [BOM_CPU_Board.csv, Back_Reset.kicad_sch, CPU.kicad_sch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]
2025-05-30 Add files via upload
    Updated to version 3. not yet built but fixes some issues that were with version 2. Will update again before it goes out for manufacture
    [BOM_CPU_Board.csv, Back_Reset.kicad_sch, CPU.kicad_sch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]
2025-06-02 Fixed some issues with memory mapping IC 25
    [Control_Logic.kicad_sch, Power_Reset.kicad_sch]
2025-06-05 Fixing up broken libraries
    not all components updated yet but working through it to minimise dependences on 3rd party libraries. Still have a bunch of DRM repairs to do as well :(
    [Back_Reset.kicad_sch, CPU.kicad_sch, CPU_Board.kicad_sch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]
2025-06-10 New PCB and library fixups
    fixed a bunch of 3rd party libraries that shouldn't be there and have done an initial PCB layout. Still using ver 2 for testing before committing to a new PCB
    [BOM_CPU_Board.csv, Back_Reset.kicad_sch, CPU.kicad_sch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]
